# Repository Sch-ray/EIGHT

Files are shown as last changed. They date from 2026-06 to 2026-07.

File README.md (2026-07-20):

# <center>EIGHT



Welcome, and thank you for your support!

This is the public repository for the **EIGHT** project. More files and resources will be released as open source over time.

> [!IMPORTANT]
> **Disclaimer:** This device is intended **only** for lawful technical learning, research, analysis, and testing by qualified users. *(You should know exactly what you're doing.)*

### Quick Start

##### 1. Power Control

- A button is located on the right side of the device.
- **Press once** to power on the device.
- **Press twice** to power off the device.

---

##### 2. Indicator LEDs

Three indicator LEDs are located on the left side of the device. From top to bottom, they are:

1. **System**
2. **Charging**
3. **Positioning**

The status indications are described below:

| Indicator | Color | On | Off | Flashing |
|---|---|----|-----|---|
| **System** | Green | Device powered on | Device powered off | Brief and rapid flashing during touch interaction or normal operation |
| **Charging** | Red | Battery charging | Charging completed | Battery fully charged and the system is being powered via USB |
| **Positioning** | Blue |  | Looking for signals | Positioning successful |

---

### Software Support

The EIGHT device is compatible with **JustCallMeKoko's ESP32 Marauder V8 firmware**.

[Marauder V8 Firmware](https://github.com/justcallmekoko/ESP32Marauder)

We are also working on a Chinese localization based on the original firmware. You can find the latest Chinese firmware here:

[Chinese Firmware](./Chinese_Firmware)

### Hardware Support

[Shell_Model](./Shell_Model)

3D enclosure models. You can now print a more beautiful ⭐ and personalized 😎 enclosure for your device!

[Developer_Board](./Developer_Board)

Developer Board assembly 🔨 and firmware flashing 💻 guide.

### Contact

My YouTube channel:

[YouTube](https://www.youtube.com/channel/UCHENkZK1oac_hoAVk4aAufA)

My BiliBili channel:

[BiliBili](https://space.bilibili.com/150167463)

If you're interested in business collaboration or have suggestions regarding the project, feel free to contact me via email:

[Email](mailto:xiao_hei666@yeah.net)

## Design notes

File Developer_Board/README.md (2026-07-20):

Welcome, and thank you for your support.

This document is intended to help advanced users and hardware enthusiasts with research and technical discussions. It is primarily written for users of the **Developer Board** version. By following this guide, you will be able to assemble your Developer Board and gain a clear understanding of its hardware design.

It is recommended that you read through the entire guide first to familiarize yourself with the assembly process and its difficulty before beginning.

> [!TIP]
> By choosing this kit, I assume that you already have some hands-on experience and technical knowledge. Therefore, the following sections focus primarily on the technical aspects rather than basic assembly skills.

### Before You Begin Assembly

1. Assembly involves certain risks. Please read this guide carefully and make sure you have a soldering iron and steady hands.
2. The entire process requires practical skills. Before you begin, make sure you are confident that you can complete the assembly successfully. Avoid damaging your device. Any damage caused by improper operation is your own responsibility.
3. Make sure your 3D printer's build plate is clean and has good adhesion. Printing the front shell with embossed text requires excellent first-layer adhesion. (When I printed the first prototypes, a dirty build plate caused many failed prints.)

### 3D Printing

You can print the enclosure you need from the [Shell_Model](../Shell_Model) directory. The folder with the highest version number contains the latest design.

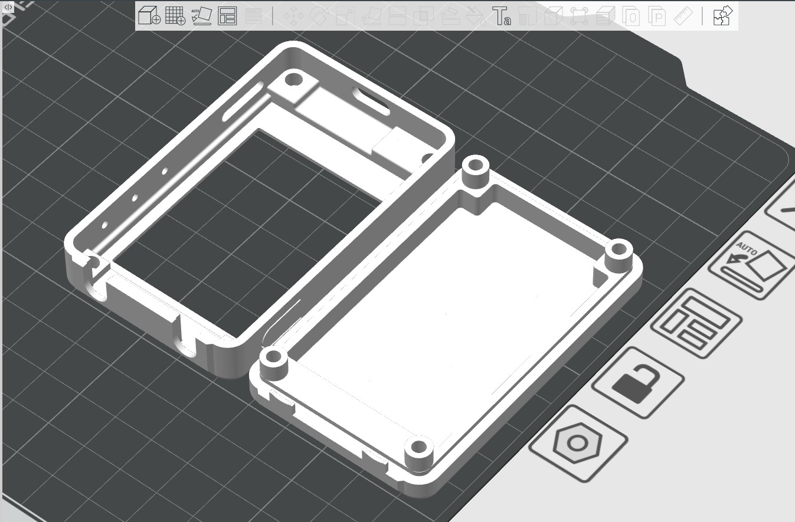
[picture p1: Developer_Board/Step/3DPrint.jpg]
Step_1


### Assembly Instructions

> [!TIP]
> Before handling the PCB, touch a grounded metal object nearby or wear an anti-static wrist strap to prevent electrostatic discharge (ESD) from damaging the board.

**1. Install the Heat-Set Inserts**

Take the four included heat-set brass inserts. Heat them using a soldering iron or another suitable heat source, then press them into the four mounting holes in the enclosure.

The inserts must **not protrude above** the surrounding surface. This means they should be fully pressed into the plastic, or even slightly deeper.

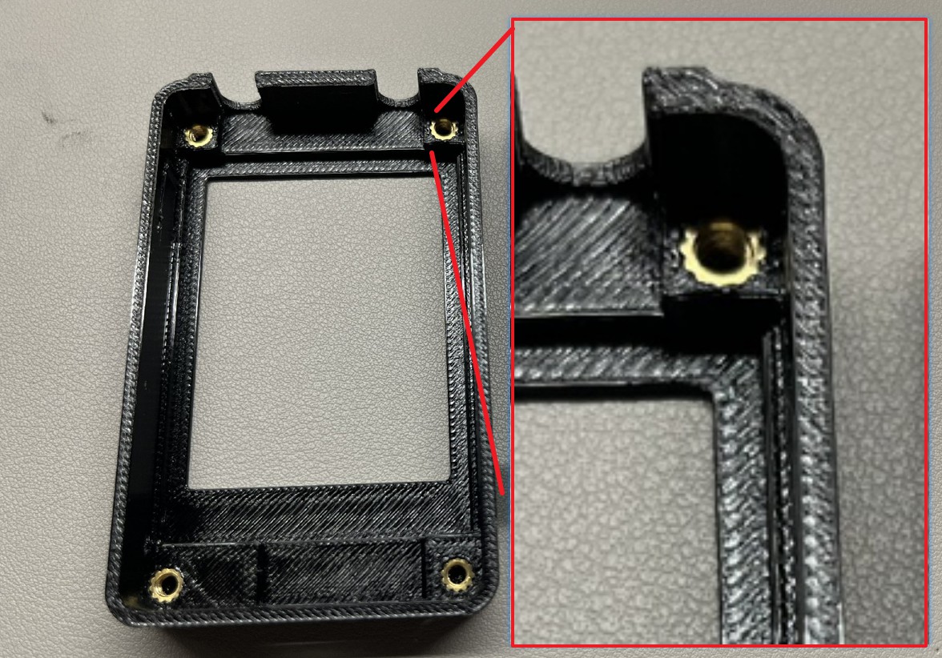
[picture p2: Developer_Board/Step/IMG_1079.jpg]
Step_2


On the side of the enclosure, there are three small windows for the status LEDs. It is recommended to fill these openings with a small amount of white or transparent glue, or even melted plastic. Their purpose is simply to keep dust out.

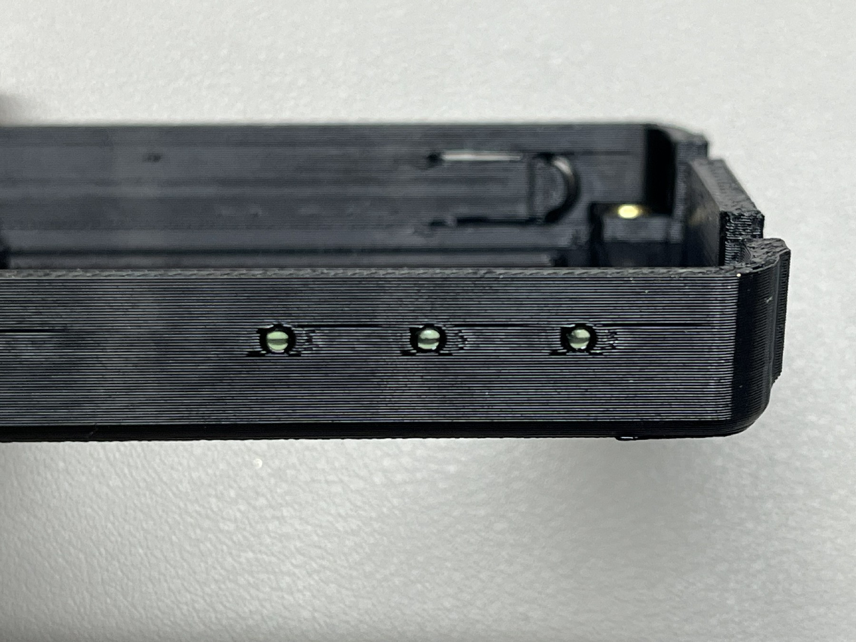
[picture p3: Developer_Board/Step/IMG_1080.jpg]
Step_6


**2. Install the PCB**

Insert the USB connector side into the enclosure first, then gently press down the antenna side until the PCB is fully seated.

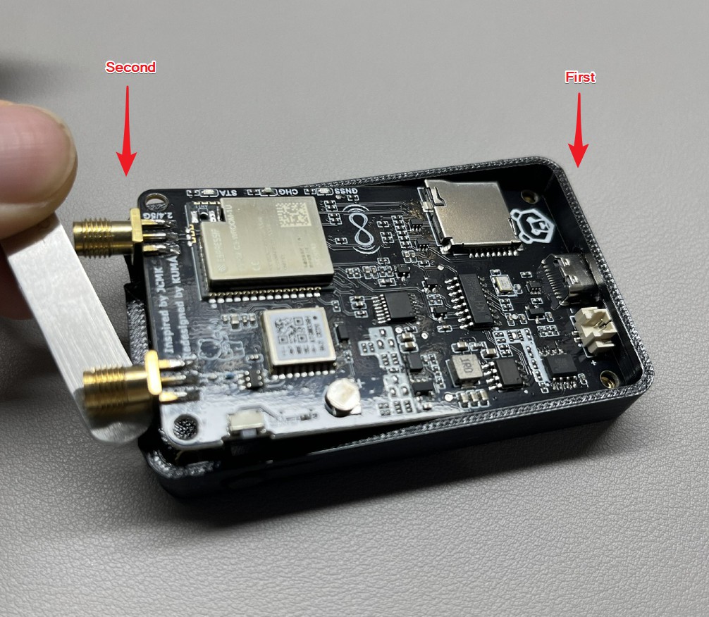
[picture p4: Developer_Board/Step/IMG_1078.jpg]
Step_1


**3. Install the Battery**

You will need to provide your own battery. The recommended specifications are:

| Item | Specification | Acceptable Range |
|---|---|---|
| **Dimensions** | 60 × 40 × 6.5 mm | The battery should be smaller than or close to the recommended dimensions in order to fit inside the enclosure. |
| **Capacity** | Approximately 2000 mAh | Use a battery with **at least 2000 mAh** capacity for safe charging operation. |
| **Connector** | JST 1.25 mm, 2-pin |

***Battery Capacity***

The PCB is configured with a maximum charging current of **1 A**. Most lithium batteries recommend a charging current of approximately **0.5C**, so a battery capacity of at least **2000 mAh** is recommended.

If you choose a smaller battery, you **must** reduce the charging current to ensure safe operation.

See the appendix: [Charging Current](#appendix-charging-current)

***Battery Mounting***

You can use thin double-sided adhesive tape to secure the battery inside the enclosure.

***Battery Connection***

If you cannot use a JST 1.25 connector, you may solder the battery directly to the PCB.

**Be extremely careful with the polarity.** The board does **not** include reverse-polarity protection, so you must ensure the positive and negative terminals are connected correctly.

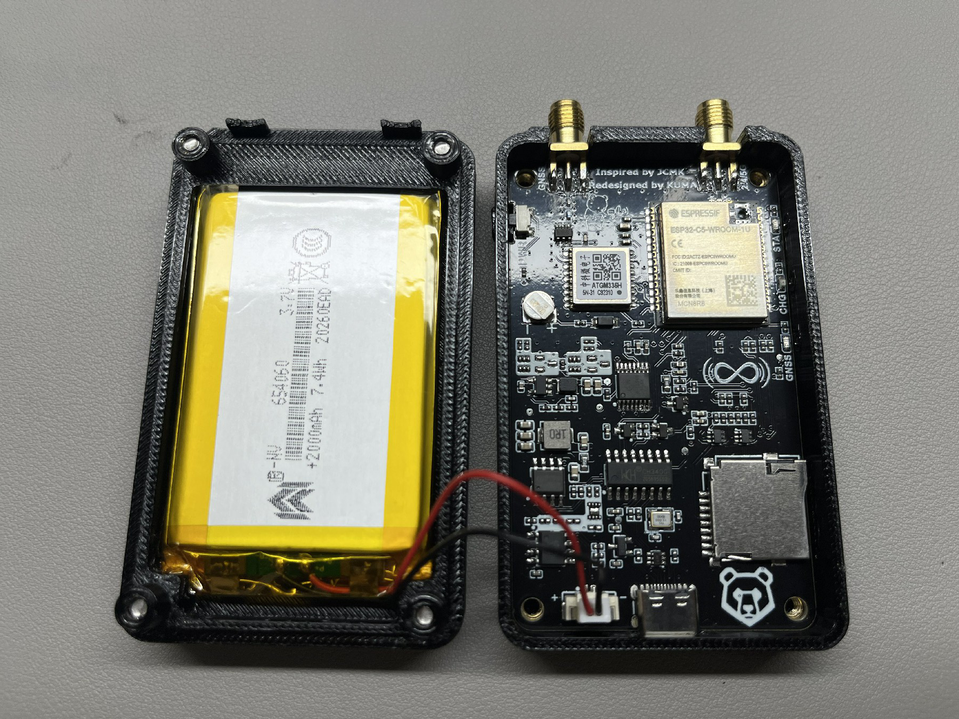
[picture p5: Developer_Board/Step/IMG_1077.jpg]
Step_2


Optionally, you may also solder a backup battery for the GNSS positioning module. Installing the backup battery can reduce the time required for satellite acquisition after power-up, but it is **not required**. Whether to install it depends on your own needs.

The backup battery model is **ML414H-IV01E**.

The schematic and installation location are shown below:

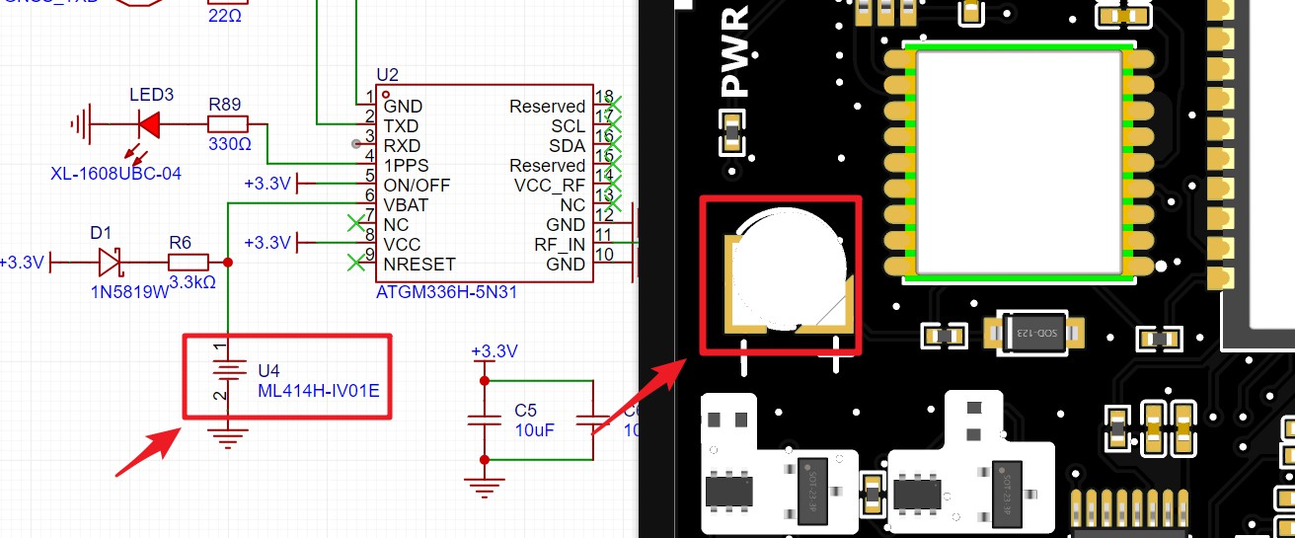
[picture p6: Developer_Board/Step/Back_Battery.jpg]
Step_3


**4. Final Assembly**

Use the four included screws to fasten the rear cover.

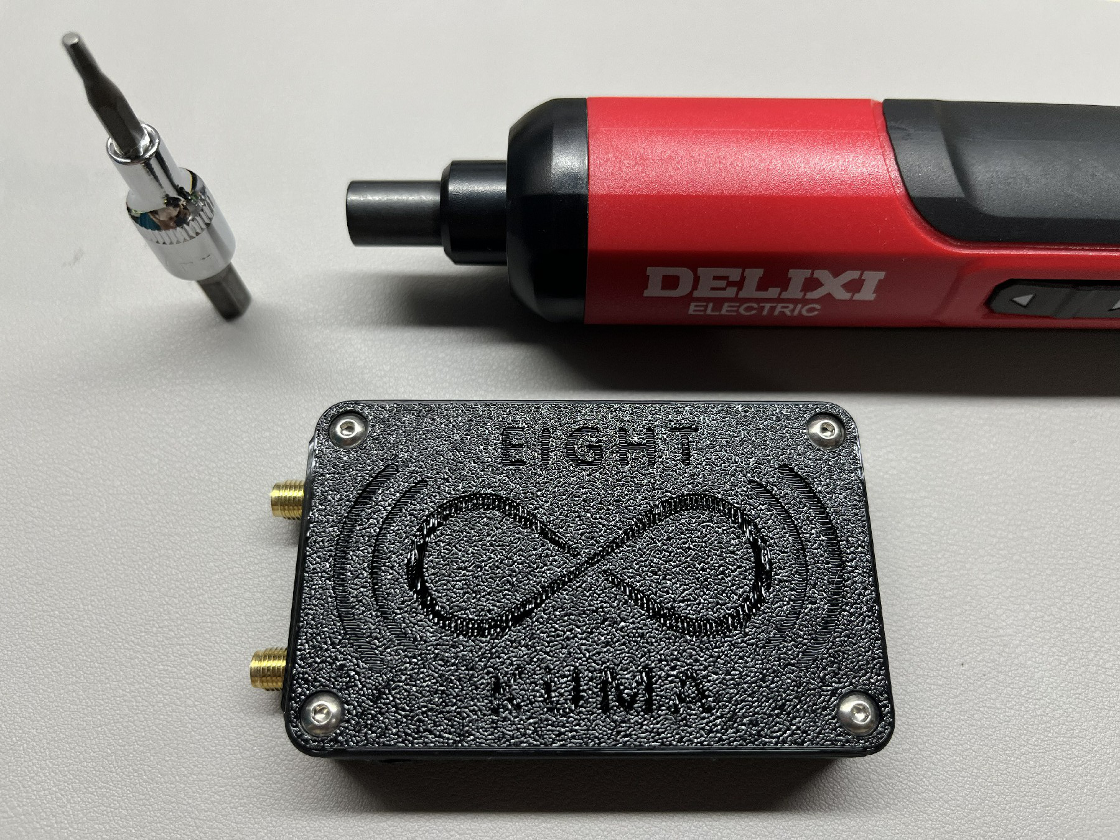
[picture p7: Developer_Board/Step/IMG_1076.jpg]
Step_4


Finally, thread the included lanyard through the hole at the lower-right corner of the enclosure for more convenient carrying.

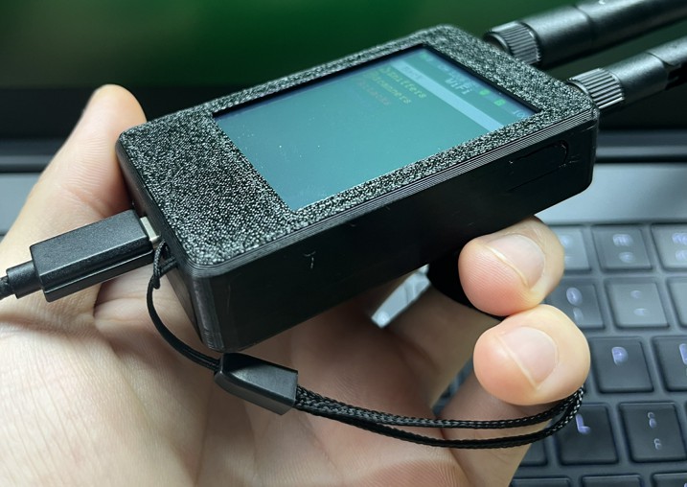
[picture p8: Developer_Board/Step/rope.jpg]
Step_8


### Firmware Flashing and Debugging Guide:

**1. Connect to the Computer**

The device is equipped with a CH340 chip and uses USB power. Therefore, regardless of whether the device is powered on or off, once you connect the device to a computer via a USB cable, a new COM port will appear. Through this COM port, you can perform firmware development, flashing, debugging, and other operations.

If no COM port appears on your computer, first check whether your USB cable supports data transmission. Then check whether the CH340 driver has been installed correctly.

You can download the CH340 driver here: [Driver](https://www.wch-ic.com/downloads/CH341SER_ZIP.html)

**2. Prepare the Flashing Tool**

You can use the official flashing tool provided by ESP32 for firmware flashing, or use other software with similar functions. In this guide, I will demonstrate using the official tool.

First, prepare **ESP32DownloadTool**.

You can download ESP32DownloadTool here: [DownloadTool](https://docs.espressif.com/projects/esp-test-tools/en/latest/esp32/production_stage/tools/flash_download_tool.html)

Then prepare the firmware you want to flash.

The **EIGHT** device is compatible with the **Marauder V8 firmware** developed by JustCallMekoko.

[Marauder V8 Firmware](https://github.com/justcallmekoko/ESP32Marauder)

At the same time, we are also working on a Chinese translation based on this firmware. You can find the latest Chinese firmware here:

[Chinese Firmware](./Chinese_Firmware)

After opening ESP32DownloadTool, select **ESP32C5** as the **ChipType**, and keep all other options at their default settings.

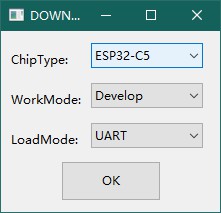
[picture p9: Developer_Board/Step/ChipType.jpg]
Step_5


In the firmware selection area above, select the required files such as **bootloader**, **firmware**, etc., and configure their corresponding addresses.

In the bottom-right corner, select the newly appeared COM port.

In the bottom-right corner, set the **BAUD** rate to the maximum value. Make sure to select the highest baud rate (this is important).

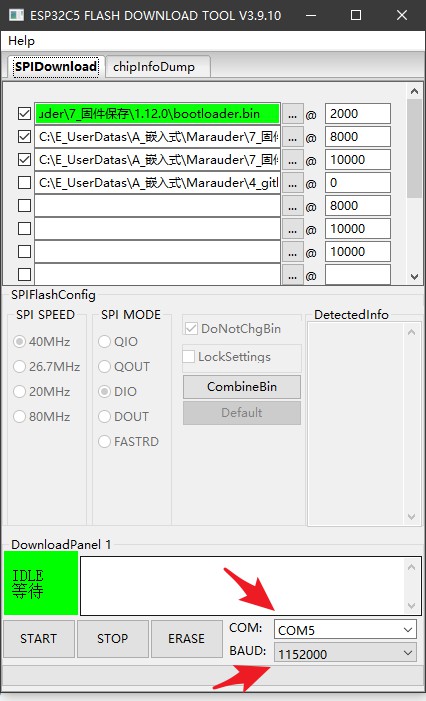
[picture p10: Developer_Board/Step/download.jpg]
Step_6


**3. Flashing the Firmware**

Please note: the device must remain powered off before starting.

First, click the **"START"** button in ESP32DownloadTool. The status will change to **"SYNC"**.

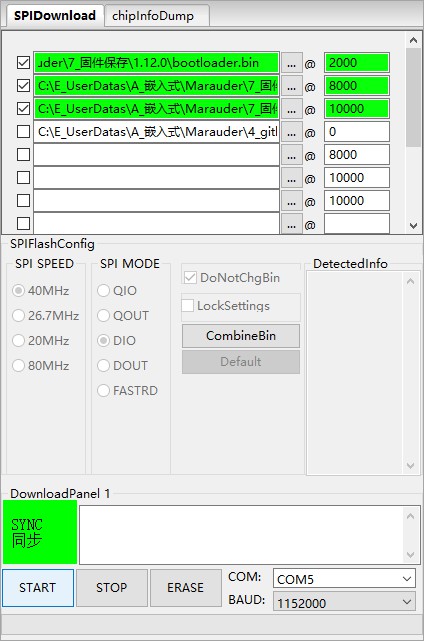
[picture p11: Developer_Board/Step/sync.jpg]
Step_9


At this moment, power on the device. The program will automatically detect the device and start flashing the firmware.

The flashing process takes approximately 10 seconds. After completion, the status will display **FINISH**.

<div>
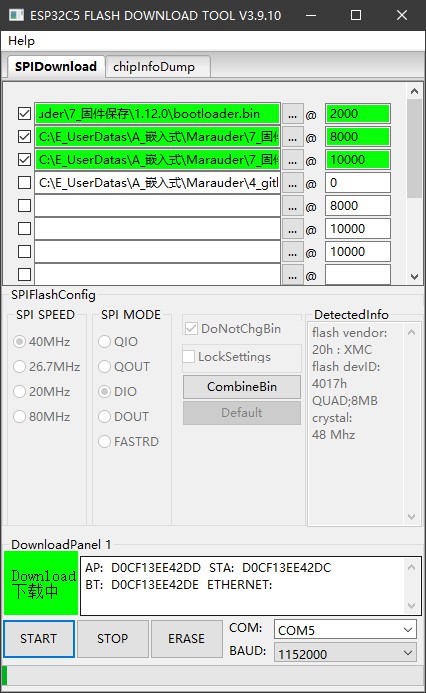
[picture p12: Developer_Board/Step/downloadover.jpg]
Step_10
  
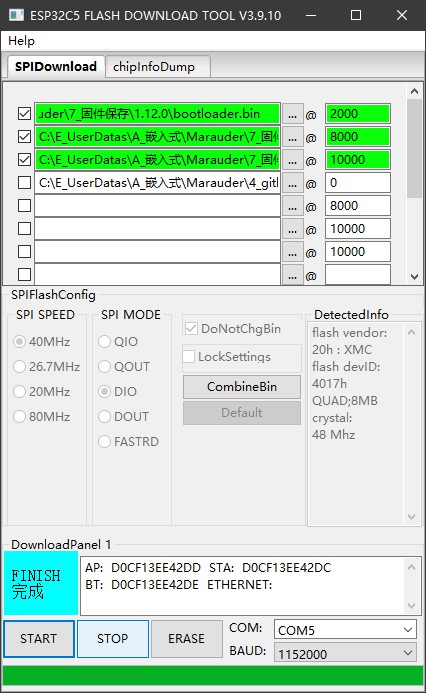
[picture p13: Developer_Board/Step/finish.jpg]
Step_11
  
</div>

After confirming that the flashing process is complete, click **"STOP"**.

Then disconnect the USB cable, power off the device, and power it on again. The newly flashed firmware will now start running.

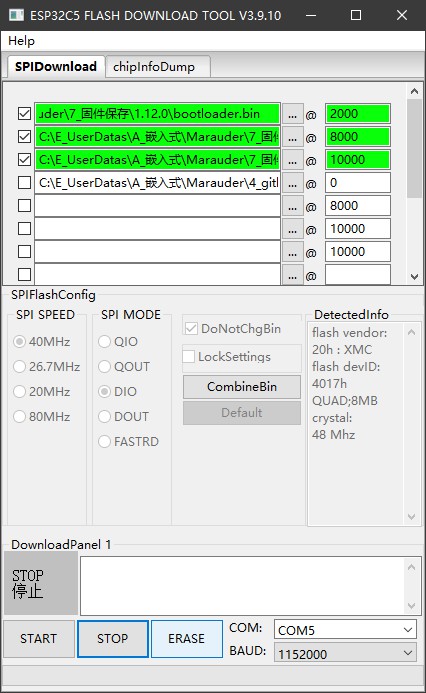
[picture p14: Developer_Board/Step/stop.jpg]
Step_10


> [!WARNING]
> During the device startup process, do not connect the device's TypeC. Otherwise, the device may enter download mode instead of running the internal user firmware.

### Appendix: Charging Current

To adjust the charging current, refer to the schematic and image below.

The maximum charging current is determined by **R35**, using the following formula:

**I(bat) = 1000 / R35**

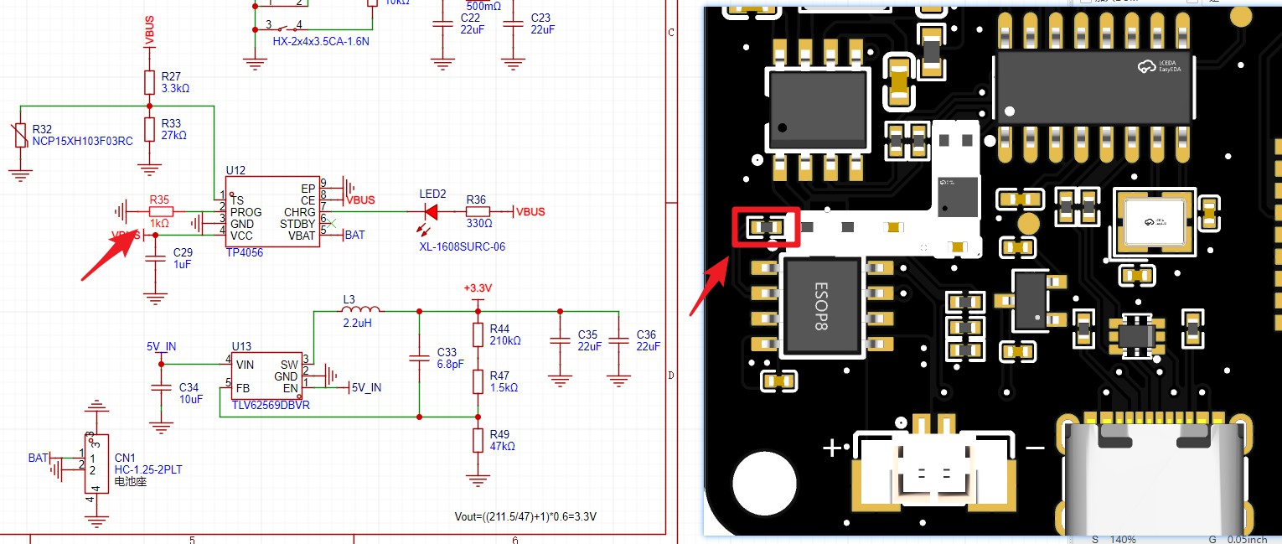
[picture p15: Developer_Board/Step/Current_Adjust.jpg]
Step_7


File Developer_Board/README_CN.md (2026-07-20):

欢迎来到这里，感谢大家支持，这个文档是为了帮助一些进阶的用户以及技术爱好者进行研究讨论的，主要针对的是Developer Board版本的用户，通过此文档，你可以将Developer Board组装起来，并且对设备的设计有清晰的了解。

建议你先看一遍操作说明，熟悉难度和操作流程，然后再开始你的旅程。

> [!TIP]
> 由于你选择了此套装，我将认为你是具备一些动手能力和技术能力的，所以在下面的描述中，我会更多的专注于技术层面。

### 开始组装设备前，你需要知道：
1、组装有风险，请仔细阅读说明，并且确保你有一个电烙铁和灵活的双手。
2、整个过程需要一定的动手能力，开始之前确定你可以搞定，不要弄坏你的设备，因为操作不当导致的后果，由你自己承担。
3、确保3D打印机的打印板干净，富有粘性，因为打印正面的文字的时候，对打印板有较高的要求（我最初打印的时候因为打印板不够干净，粘性较差，失败了很多次）。

### 3D打印说明：
你可以通过[Shell_Modell](../Shell_Model)目录来打印你所需要的外壳，最大的数字代表最新的版本。
Step_1

### 组装说明：

> [!TIP]
> 开始之前，你可以触摸附近的接地金属，或者使用静电手环，避免静电损坏电路板。

**1、安装螺母**
取出附送的四个热熔螺母，使用火源或者电烙铁加热，并压入到壳体的四个孔洞里，螺母不能高于孔洞周围的平面，这意味着你必须把螺母彻底按压进去，或者更深。
Step_2

在设备侧面有3个指示灯的窗口，建议你使用一些白色或透明的胶水，甚至是融化的塑料填充这些孔洞即可，它们的作用只是防尘。
Step_6

**2、安装电路板**
你需要先把USB口的一侧安装进去，然后再将天线的一侧按压下去。
Step_1

**3、安装电池**
你需要自己准备电池，建议使用以下的电池参数：
| 名称 | 内容 | 可以容许的范围 |
|---|---|---|
| **尺寸** | 60 × 40 × 6.5 mm | 你的电池尺寸必须小于或者接近推荐的尺寸，才能安装到壳体内部。 |
| **容量** | 约 2000 mAh | 你的电池必须使用2000mAh或者更大的容量，才能安全的使用 |
| **接口** | JST 1.25 mm, 2-pin |

***电池的容量：***
PCB设计时，电池的最大充电电流设置为了1安培，一般的锂电池允许0.5C的充电电流。所以建议使用至少2000mAh的电池。如果你选择的更小的容量，那么你必须修改充电电流以确保安全。
详见附录[充电电流](#附录：充电电流)
***电池的固定：***
你可以使用一些比较薄的双面胶将电池固定到壳体上。
***电池的连接：***
如果你无法通过JST1.25进行连接，你可以直接将电池焊接到PCB上，但是务必注意正负极，电路上没有设计反接保护，你必须确保正负极的正确。
Step_2

另外，你也可以额外焊接定位模组的备用电池，增加备用电池后，可以缩短定位时间，但这不是必须的，所以你可以根据自己的需求选择是否安装，备用电池的型号是“ML414H-IV01E”。这是备用电池的电路图和位置：
Step_3

**4、最后的安装**
取出附送的4个螺丝，将后盖板拧紧即可。
Step_4

最后，你可以将附送的挂绳穿入到壳子右下角的孔洞内，可以更方便的使用设备。
Step_8

### 固件烧录及调试说明：
**1、连接电脑**
设备板载了CH340芯片，并且使用的是USB的电源，所以无论开机还是关机，只要你将设备通过USB线连接到电脑，将会出现新的COM设备，通过COM口可以进行程序开发，烧录，调试等功能。如果你的电脑没有出现COM设备，首先检查你的数据线是否具备数据传输功能，然后检查电脑是否已经安装了CH340的驱动程序。

这是CH340的驱动下载链接：[Driver](https://www.wch-ic.com/downloads/CH341SER_ZIP.html)

**2、准备烧录工具**
你可以通过ESP32官方提供的烧录工具进行固件的烧录，或者使用类似功能的其他软件，我会使用官方的工具进行演示。
首先准备好ESP32DownloadTool。
这是ESP32DownloadTool的下载链接：[DownloadTool](https://docs.espressif.com/projects/esp-test-tools/en/latest/esp32/production_stage/tools/flash_download_tool.html)

然后准备好你需要的固件。

EIGHT设备兼容JustCallMekoko的Marauder V8固件。
[Marauder V8固件](https://github.com/justcallmekoko/ESP32Marauder)

与此同时，我们也在基于此固件进行汉化工作，你可以在这里找到目前最新的汉化固件。
[中文固件](./Chinese_Firmware)

当你打开ESP32DownloadTool后，ChipType选择ESP32C5,其余选项保持默认。
Step_5
在上面的固件选择框里选择你需要烧录的bootload、firmware等文件。并设置好地址。
在右下角COM口选择刚刚出现的新COM口。
在右下角的BAUD选择最大的波特率，一定要选择最大的（这很重要）。
Step_6

**3、程序烧录**
这里需要注意，请务必先让设备保持在关机状态，然后点击ESP32DownloadTool的“START”，按钮会显示"SYNC同步"。
Step_9
这个时候将设备开机，程序就会自动识别到，然后自动开始烧录，大概耗时10秒钟即可烧录完毕。完成后就会显示FINISH。
<div>
  Step_10
  Step_11
</div>

确认完成后，点击“STOP”，然后断开USB，先将设备关机，然后再开机，即可运行刚刚烧录的固件。
Step_10

> [!WARNING]
> 设备在开机启动阶段时，不可以连接设备的TypeC接口，否则设备可能进入下载模式，而不是运行内部用户固件。

### 附录：充电电流
关于充电电流调节的部分，你可以参考这部分电路图和图片指示。通过调整R35可以调节最大充电电流，计算方式是“I(bat)=1000 / R35”
Step_7

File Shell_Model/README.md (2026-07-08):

Welcome, and thank you for your support!

If you have a 3D printer, you can now print a more beautiful ⭐ and personalized 😎 enclosure for your device! If you have enough time, you can also choose finer print settings for even better quality.

I printed the enclosure using **PETG**. With a properly calibrated printer, the print quality is quite good.

> [!WARNING]
> **Warning:** Disassembling the enclosure may damage your device. Any risks or damage resulting from the disassembly are entirely your own responsibility.

### Before You Print Your Own Enclosure

1. Disassembly and reassembly involve certain risks. Please read this guide carefully and make sure you have a soldering iron and steady hands.
2. Replacing the enclosure requires some hands-on experience. Before you begin, make sure you are confident you can complete the process without damaging your device. Any damage caused during disassembly is your own responsibility.
3. Make sure your 3D printer's build plate is clean and has good adhesion. Printing the front shell with embossed text requires excellent first-layer adhesion. (When I printed the first prototypes, a dirty build plate caused many failed prints.)
4. Be prepared for some handmade imperfections inside the device. Since each unit is assembled and soldered by hand, you may notice some signs of manual workmanship. 😄

### 3D Printing

You can print the enclosure you need from the [Shell_Model](././Shell_Model) directory. The folder with the highest version number contains the latest design.

Step_1

### Disassembly and Reassembly

> [!TIP]
> Before disassembling the device, touch a grounded metal object nearby or wear an anti-static wrist strap to prevent electrostatic discharge (ESD) from damaging the PCB.

**1. Remove the Top Cover**

On the back of the device, you will see four obvious screws. Remove them using a screwdriver.

Step_1

You will then have access to the internal PCB.

Step_2

**2. Disconnect the Cables**

Disconnect the battery connector.

Also, **don't forget to remove the microSD (TF) card** before continuing.

**3. Remove the PCB**

Lift the PCB upward from the antenna connector side first.

Once lifted, the PCB can be removed from the enclosure.

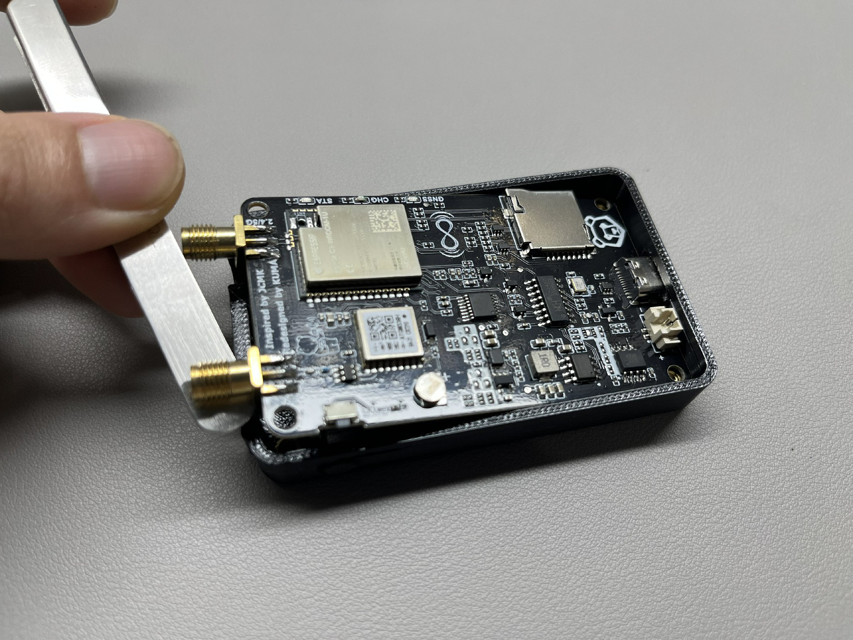
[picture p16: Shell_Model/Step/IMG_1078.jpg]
Step_3


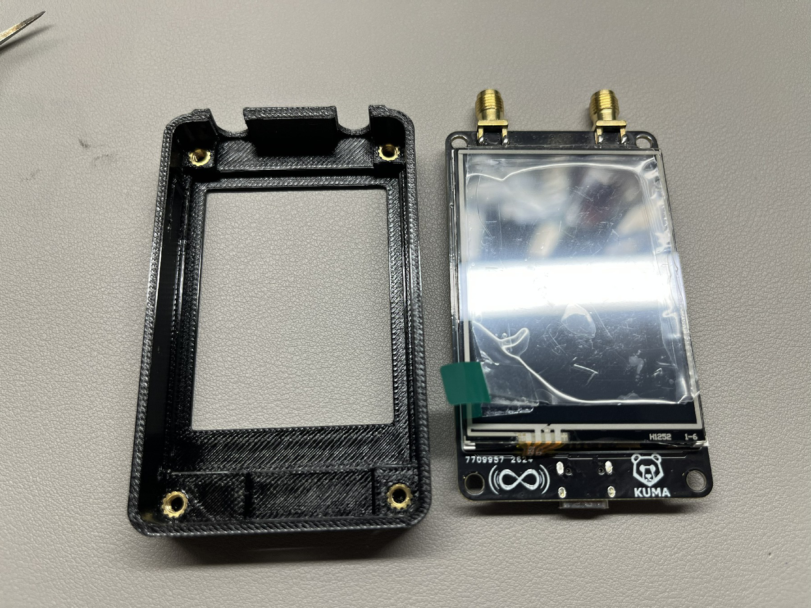
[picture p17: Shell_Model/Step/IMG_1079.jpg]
Step_4


**4. Remove the Remaining Components**

The enclosure also contains four metal heat-set inserts.

If you want to reuse them in your new enclosure, heat them with a soldering iron (or another suitable tool) and carefully pry them out.

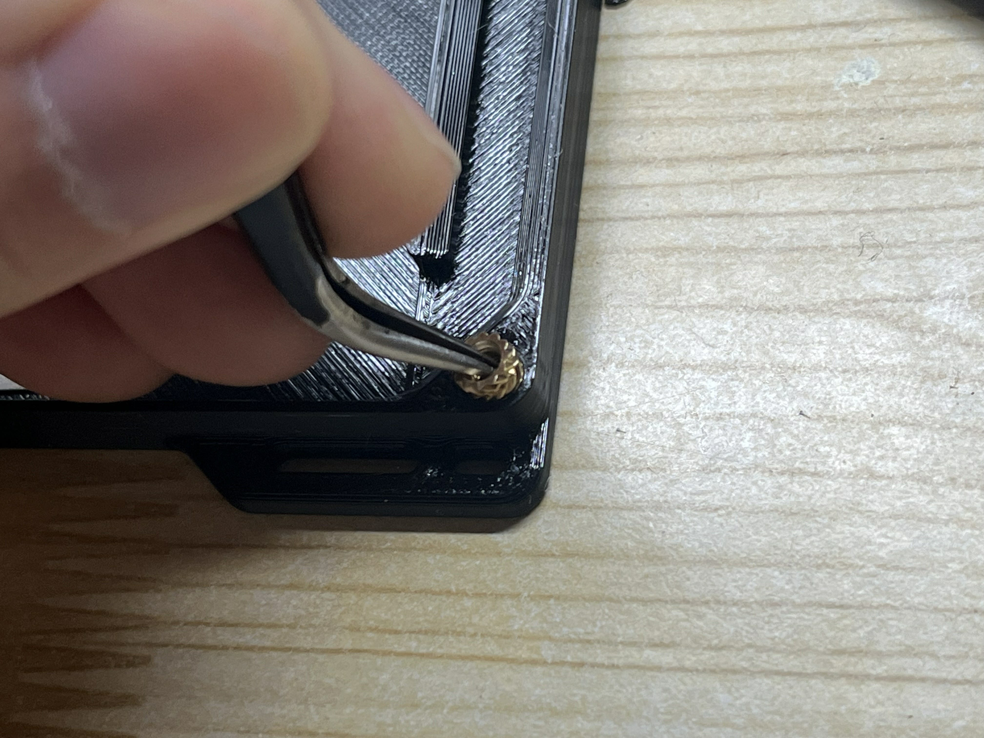
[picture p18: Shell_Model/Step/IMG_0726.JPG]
Step_5


One final detail:

On the side of the enclosure are three small openings for the status LEDs. I originally used tiny glass beads as transparent "windows."

You may choose to reuse them by gently heating them during removal and installation.

However, because the glass beads are extremely small and somewhat difficult to handle, I recommend simply filling the openings with a small amount of white or transparent glue instead. Melted plastic can also be used if preferred.

Step_6

**5、Last Step**
Now simply perform the above steps in reverse order to install everything into your new enclosure.

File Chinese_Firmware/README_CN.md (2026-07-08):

> [!IMPORTANT]
> 再次声明：设备仅用作专业人员的合法技术学习和分析测试（你最好知道你自己在干什么）。

### 固件烧录及调试说明：
**1、连接电脑**
设备板载了CH340芯片，并且使用的是USB的电源，所以无论开机还是关机，只要你将设备通过USB线连接到电脑，将会出现新的COM设备，通过COM口可以进行程序开发，烧录，调试等功能。如果你的电脑没有出现COM设备，首先检查你的数据线是否具备数据传输功能，然后检查电脑是否已经安装了CH340的驱动程序。

这是CH340的驱动下载链接：[Driver](https://www.wch-ic.com/downloads/CH341SER_ZIP.html)

**2、程序烧录**
你可以通过ESP32的烧录工具进行固件的烧录，首先准备好你需要的固件。然后打开ESP32DownloadTool。

ChipType选择ESP32C5,其余选项保持默认。

Step_5

在上面的固件选择框里选择目录下的“firmware.factory.bin”文件。将右边的地址设置为0。

> [!TIP]
> 这里与英文固件不同，将所有bin文件都集成到一个bin内，所以只需要烧录一个文件。

在右下角COM口选择刚刚出现的新COM口。
在右下角的BAUD选择最大的波特率，一定要选择最大的（这很重要）。
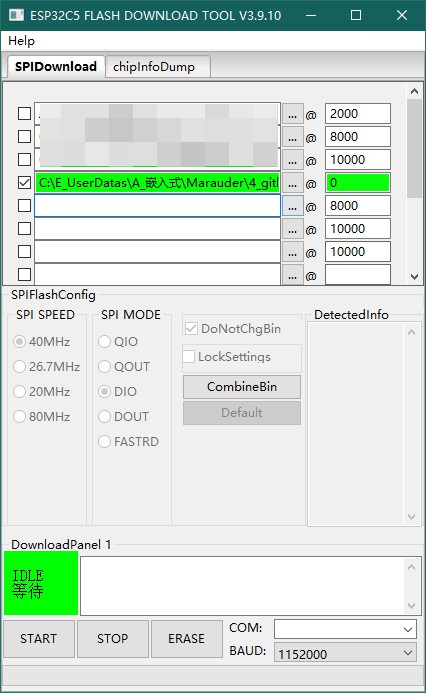
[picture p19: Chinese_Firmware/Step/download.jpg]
Step_6


这是ESP32DownloadTool的下载链接：[DownloadTool](https://docs.espressif.com/projects/esp-test-tools/en/latest/esp32/production_stage/tools/flash_download_tool.html)

先让设备保持在关机状态，点击ESP32DownloadTool的“START”，程序会处于等待状态，这个时候按一次设备电源按键，然后自动开始烧录，大概耗时10秒钟。

烧录完成后，断开USB，关机，然后再开机，即可运行刚刚烧录的固件。

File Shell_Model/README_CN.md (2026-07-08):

欢迎来到这里，感谢大家支持，如果你有一台3D打印机，现在你可以为自己打印更漂亮⭐更具个人特色😎的外壳!并且如果你有足够的时间，可以选择更精细的打印精度。

我在打印时使用了PETG材料，如果打印机设置正确的话，打印效果还算不错。

> [!WARNING]
> 警告，拆卸壳体有可能损坏设备，你需要自己承担后果。

### 开始打印自己的外壳前，你需要知道：
1、拆装有风险，请仔细阅读说明，并且确保你有一个电烙铁和灵活的双手。
2、更换和安装外壳需要一定的动手能力，开始之前确定你可以搞定，不要弄坏你的设备，因为拆卸导致的后果，由你自己承担。
3、确保3D打印机的打印板干净，富有粘性，因为打印正面的文字的时候，对打印板有较高的要求（我最初打印的时候因为打印板不够干净，粘性较差，失败了很多次）。
4、做好心理准备，内部由于是手工组装焊接的，所以有可能会有手工的痕迹~（还要什么自行车:roll_eyes:~）

### 3D打印说明：
你可以通过[Shell_Modell](././Shell_Model)目录来打印你所需要的外壳，最大的数字代表最新的版本。
Step_1

### 拆卸及组装说明：

> [!TIP]
> 拆卸之前，你可以触摸附近的接地金属，或者使用静电手环，避免静电损坏电路板。

**1、拆掉顶壳**
在设备背面，你可以看到非常明显的4个螺丝，使用螺丝刀将其拆掉。
Step_1
然后你会看到设备的内部电路板。
Step_2

**2、断开连接线**
拔掉电池连接线，然后记得一定要拆除tf卡。

**3、拿出主板**
从天线插口一侧将电路板向上抬起来。然后就可以取出电路板了。
Step_3
Step_4

**4、取出其他配件**
设备外壳还有4个金属的热熔螺母，如果你需要在新的壳子上继续使用的它，那么也需要拆下来，使用电烙铁等工具加热后撬出来。
Step_5

还有最后一个东西，在设备侧面有3个指示灯的孔，我使用了一些小型玻璃珠来充当“窗口”，你可以选择循环利用他们，在拆除和安装的或者中，只需要稍微加热这些玻璃珠。

不过因为玻璃珠特别小，操作难度大。建议你使用一些白色或透明的胶水替代，甚至是塑料填充这些孔洞即可。
Step_6

**5、最后一步**
现在，把这些步骤再反向重复一遍，装回到新的壳体里。

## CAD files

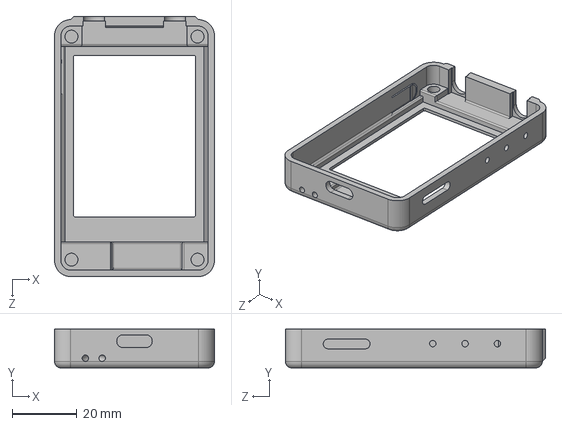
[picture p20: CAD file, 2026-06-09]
Shell_Model/V1/Top.STEP
49.5 x 12.0 x 80.5 mm

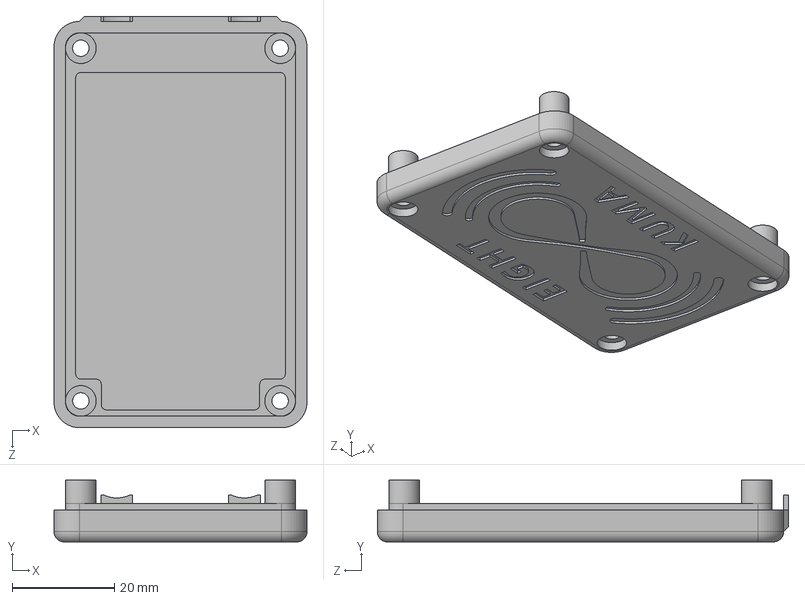
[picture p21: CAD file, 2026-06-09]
Shell_Model/V1/Botton.STEP
49.5 x 12.1 x 80.5 mm
